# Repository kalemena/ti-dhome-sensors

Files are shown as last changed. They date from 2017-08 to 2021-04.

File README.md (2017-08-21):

# ti-dhome-sensors

Sensors library (use with ti-dhome home automation)

This is custom Sensor unit handler used to capture plenty of metrics and send them over the air to central server.

The initial model units are heavily inspired from the venerable JeeLab Room node.

Sensors are placed in each room and are each monitoring few of below metrics:
* Temparature (1 or more sensor per unit)
* Humidity
* Pressure
* Light
* Move
* TODO: plant humidity
* TODO: gaz
* TODO: pH-meter / CO2

Eventualy, the various measure will serve for:
* control electric heaters
* control VMC (home motorized air flow controler)
* alarms on various actions (plants, etc)

# Hardware

Central board:
* JeeLink (full enclosure, see JeeLab web site)
or
* TBD: Arduino nano 3.3v + radio (RFM12B or RFM69CW)

Base board for sensors:
* model 1 : RFM12B (868Mhz) JeeNode (arduino compatible + radio, see JeeLab web site)
* model 2 : RFM69CW (868Mhz) Arduino pro mini 3.3v or clone

* Batteries: 3xAA or 1xAA+3.3v step-up, or other

Sensors (1+ per board):
* Temparature: DS18B20 (waterproof or not: for some reason waterproof is cheaper!)
* Temparature + Humidity: SHT11 or DHT22 (bigger but with case, and cheaper!)
* Pressure: BMP85
* Light: standard LDR
* Move: TBD
* Plant humidity: TBD
* Gaz: TBD
* pH-meter / CO2: TBD

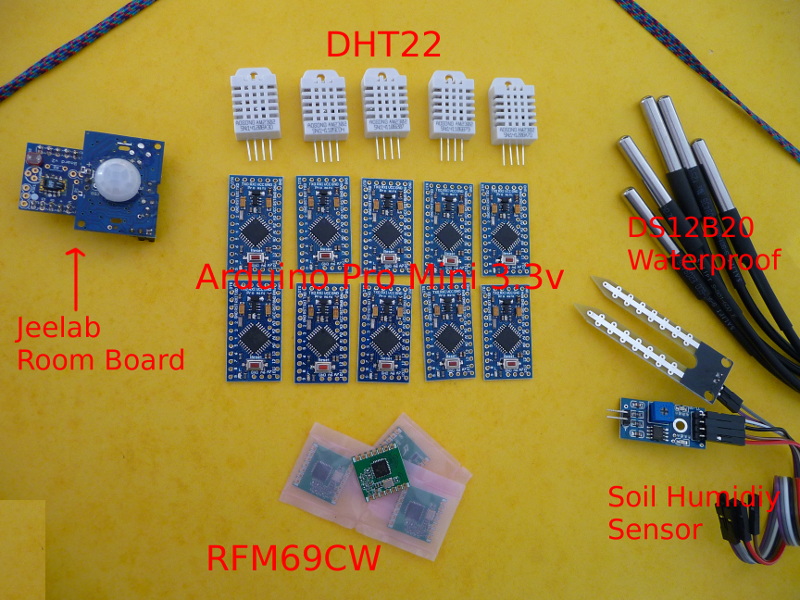
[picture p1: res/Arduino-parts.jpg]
Parts


# Models

## Model 1

[Model 1](model-1) was done in 2010, based entirely on JeeLab work.

## Model 2

[Model 2](model-2) was done in 2015, with little evolution from model 1.

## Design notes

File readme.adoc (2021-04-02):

:toc:

ifdef::env-github[]
:imagesdir: res
endif::[]

= ti-dhome-sensors

Arduino-based sensors library.

This is DIY Sensor unit used to capture plenty of metrics and send them over the air to central unit server.

NOTE: This project is part of a wider link:https://github.com/kalemena/ti-dhome[TiDhome Home Automation] project.

The initial model units are heavily inspired from the venerable JeeLab Room node.

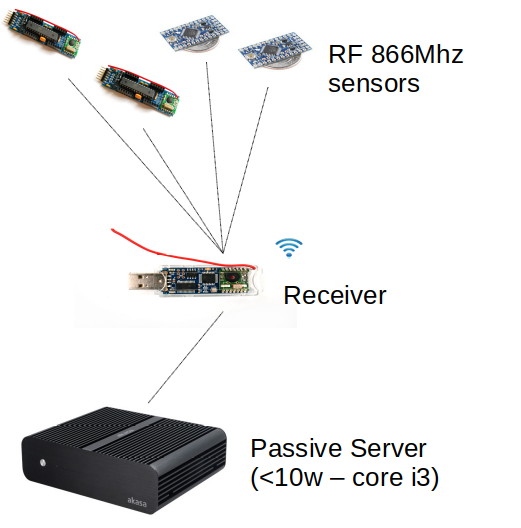
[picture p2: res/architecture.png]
Architecture


== Usage

Sensors are placed in each room and are each monitoring few of below metrics:

* Temparature (1 or more sensor per unit)
* Humidity
* Pressure
* Light
* Move
* TODO: plant humidity
* TODO: gaz
* TODO: pH-meter / CO2

Eventualy, the various measure serve to:

* control electric heaters
* control VMC (home motorized air flow controler)
* alarm on various actions (plants, etc)
* etc

== Hardware

*Central board:*

* JeeLink (full enclosure, see link:https://www.digitalsmarties.net/products/jeelink[JeeLab] web site)

Base board for *sensors model*:

* model 1 : RFM12B (868Mhz) JeeNode (arduino compatible + radio, see JeeLab web site)
* model 2 : RFM69CW (868Mhz) Arduino pro mini 3.3v or clone

*Batteries:* 3xAA or 1xAA+3.3v step-up, or other

*Sensors* (one or more per board):

* Temperature: DS18B20 (waterproof or not)
* Temparature + Humidity: SHT11, DHT22, HTU21
* Pressure: BMP85
* Light: standard LDR
* Move: TBD
* Plant humidity: TBD
* Gaz: TBD
* pH-meter / CO2: TBD

Parts

== Models

=== Model 1

link:model-1[Model 1] was done in 2010, based entirely on JeeLab work.

=== Model 2

link:model-2[Model 2] was done in 2015, with little evolution from model 1.

== More readings

* link:https://www.instructables.com/id/LEIDS-Low-Energy-IOT-Door-Sensor[Check this circuit]

.To Check
[%collapsible]
====
* link:https://www.mysensors.org/apidocs-beta/MyHwESP32_8h_source.html[]
* link:https://www.mysensors.org/build/connect_radio[]
* link:https://github.com/mysensors/MySensors/tree/master[]
====

.Fun IoT projects
[%collapsible]
====
* link:https://www.instructables.com/id/Save-Water-With-the-Shower-Water-Monitor/[]
* link:https://www.instructables.com/id/Battery-Powered-Door-Sensor-With-Home-Automation-I[]
* link:https://www.instructables.com/Autonomous-Solar-powered-Irrigation-Monitoring-Sta[]
====

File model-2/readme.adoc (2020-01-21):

:toc:

ifdef::env-github[]
:imagesdir: ../res
endif::[]

= Description

This sensor was done in 2015, with few evolution from model 2.

The sensors are RFM12B 868Mhz radio transceivers.

One central transceiver receives all measures from all remote sensors.  

= Hardware

Receiver listens on USB tty port:

JeeLink

Plenty emmiter send data using below as base board.

Arduino pro mini 3.3v

Plenty sensors as seen on main page.

Wiring sensors is described at https://github.com/kalemena/arduino-res[arduino-res]

== Breadboard design

Basically initial boards are done like below:

Wiring Breadboard 3xAAA

Wiring Breadboard 1xAAA

== PCB design

Going from Breadboard to PCB using simple double side link:src/pcb[PCB]:

Breadboard

PCB sample look like below:

PCB

Model 2 Top Model 2 Bottom

= Implementation

== How-To - central receiver node

* Open sketch from folder 'src/sketches/sensor_rx_unit/' into Arduino IDE

* Upload sketch to radio-enabled device

* Connect receiver node to USB and find which usb resource connected

[source,bash]
----
$ lsusb
$ dmesg
----

* Allow user access to resource and set speed

[source,bash]
----
$ sudo stty -F /dev/ttyUSB0 57600
$ sudo chmod 777 /dev/ttyUSB0
$ cat /dev/ttyUSB0
----

* Edit test script to point to USB devices or point Node-Red to correct USB device.

== How-To - remote sensor nodes

* Open sketch from folder 'src/sketches/sensor_trx_unit/' into Arduino IDE

* Modify sketch to match sensor devices plugged onto the arduino (ensure pins are correct)

* Upload sketch to radio-enabled device

* ... let it submit metrics over the air ...

== Tests

A small javascript code is done to grab on tty USB port and submit to mqtt queue.

Go to folder 'src/js/' and run below commands:

[source,bash]
----
$ npm install serialport
$ npm install mqtt
$ node pub-sensors.js
----

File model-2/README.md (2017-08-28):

# Description

This sensor was done in 2015, with few evolution from model 1.

The sensors are RFM12B 868Mhz radio transceivers.

One central transceiver receives all measures from all remote sensors.  

# Hardware

Receiver listens on USB tty port:

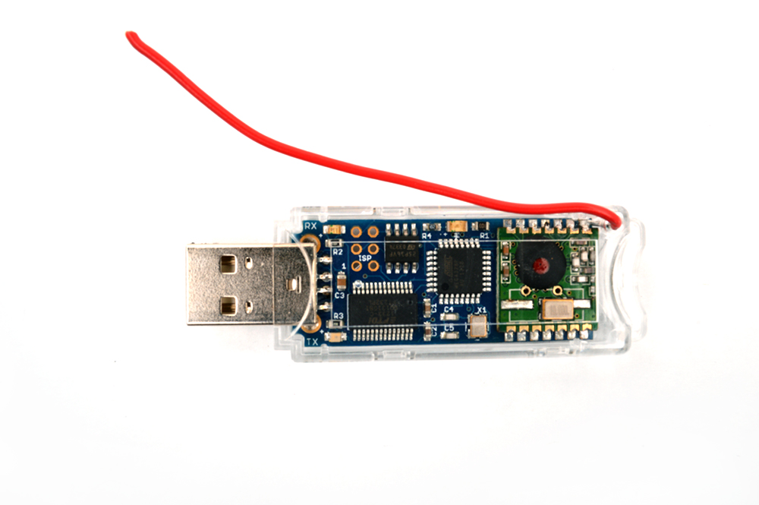
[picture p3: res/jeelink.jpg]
JeeLink


Plenty emmiter send data using below as base board.

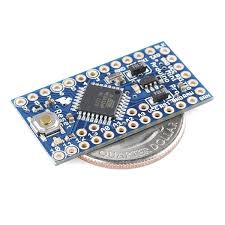
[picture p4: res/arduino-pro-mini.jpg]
Arduino pro mini Arduino Pro Mini 3.3v


Plenty sensors as seen on main page.

Wiring sensors is described at [arduino-res](https://github.com/kalemena/arduino-res)

## Breadboard design

Basically initial boards are done like below:

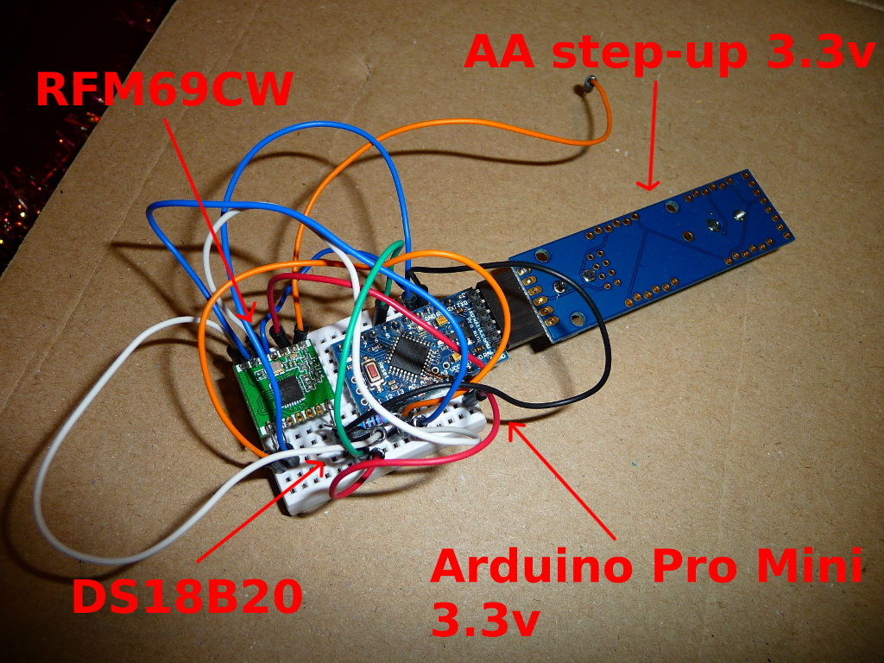
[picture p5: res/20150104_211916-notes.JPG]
Wiring Breadboard 3xAAA


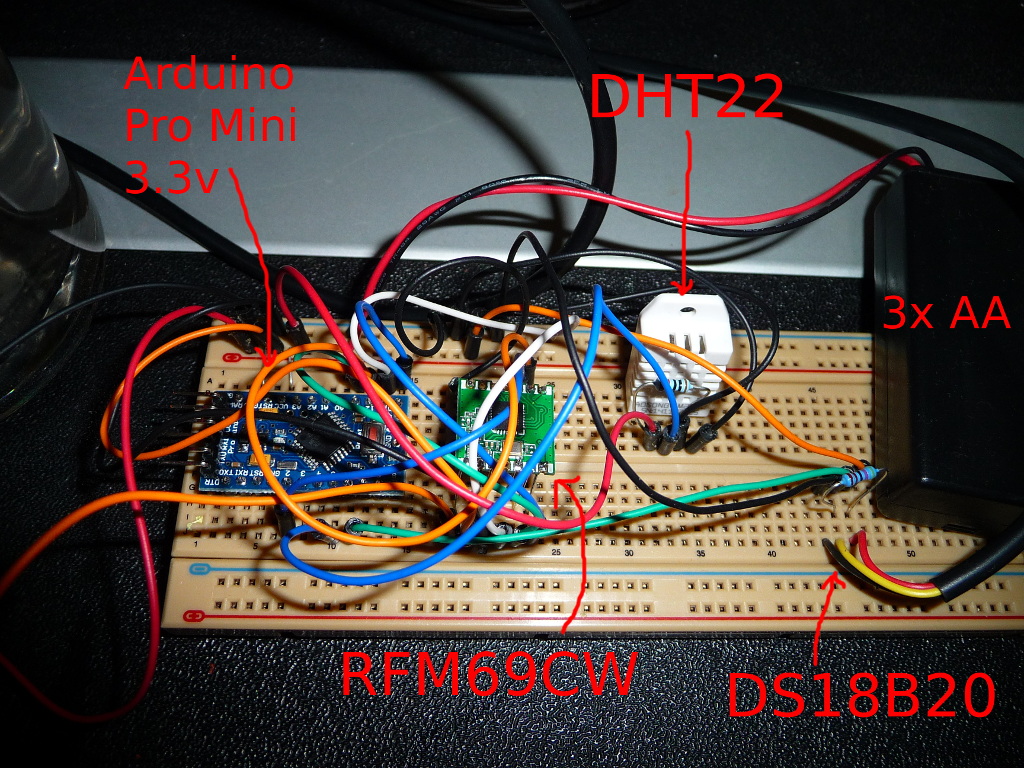
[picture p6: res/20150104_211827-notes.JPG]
Wiring Breadboard 1xAAA


## PCB design

Going from Breadboard to PCB using simple double side PCB:

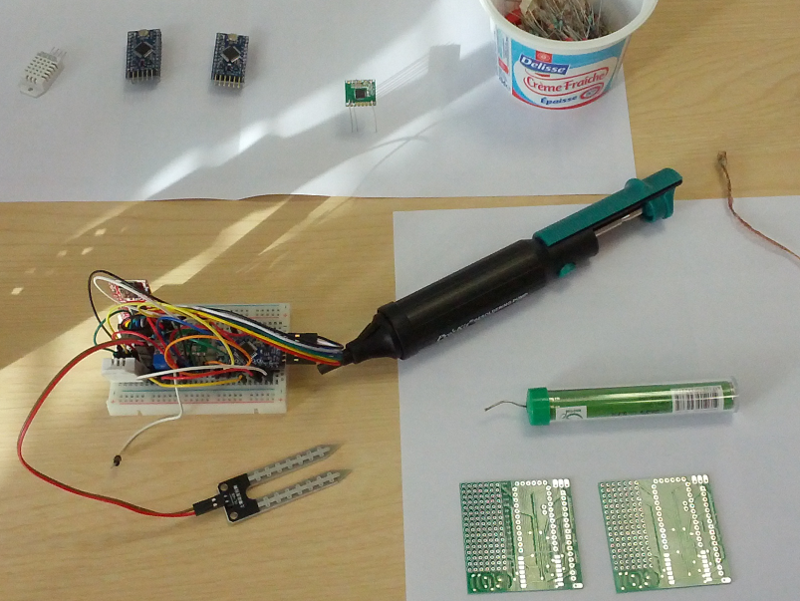
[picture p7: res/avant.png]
Breadboard


PCB sample look like below:

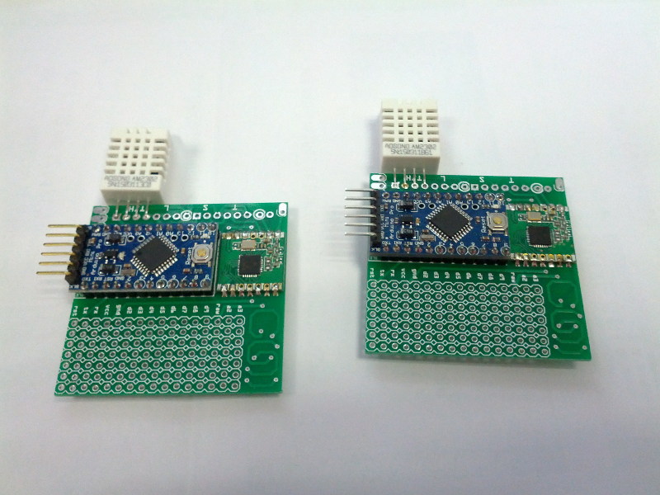
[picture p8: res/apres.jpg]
PCB


# Implementation

## How-To - central receiver node

* Open sketch from folder 'src/sketches/sensor_rx_unit/' into Arduino IDE

* Upload sketch to radio-enabled device

* Connect receiver node to USB and find which usb resource connected

```js
$ lsusb
$ dmesg
```

* Allow user access to resource and set speed

```js
$ sudo stty -F /dev/ttyUSB0 57600
$ sudo chmod 777 /dev/ttyUSB0
$ cat /dev/ttyUSB0
```

* Edit test script to point to USB devices or point Node-Red to correct USB device.

## How-To - remote sensor nodes

* Open sketch from folder 'src/sketches/sensor_trx_unit/' into Arduino IDE

* Modify sketch to match sensor devices plugged onto the arduino (ensure pins are correct)

* Upload sketch to radio-enabled device

* ... let it submit metrics over the air ...

## Tests

A small javascript code is done to grab on tty USB port and submit to mqtt queue.

Go to folder 'src/js/' and run below commands:

```js
$ npm install serialport
$ npm install mqtt
$ node pub-sensors.js
```

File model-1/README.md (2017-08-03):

# Description

This sensor was done in 2010, based entirely on JeeLab work.

The sensors are RFM12B 868Mhz radio transceivers.

One central transceiver receives all measures from all remote sensors.  

# Hardware

Receiver listens on USB tty port:

JeeLink

Plenty emmiter send data using below as base board.

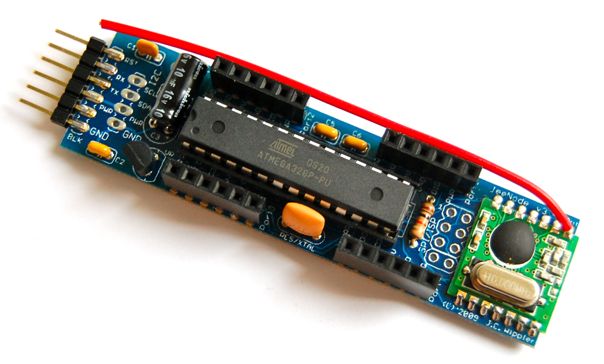
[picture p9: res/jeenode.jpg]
JeeNode


Plenty sensors as seen on main page.

Wiring sensors is described at [arduino-res](https://github.com/kalemena/arduino-res)

# Implementation

## How-To - central receiver node

* Open sketch from folder 'src/sketches/sensor_rx_unit/' into Arduino IDE

* Upload sketch to radio-enabled device

* Connect receiver node to USB and find which usb resource connected

```js
$ lsusb
$ dmesg
```

* Allow user access to resource and set speed

```js
$ sudo stty -F /dev/ttyUSB0 57600
$ sudo chmod 777 /dev/ttyUSB0
$ cat /dev/ttyUSB0
```

* Edit test script to point to USB devices or point Node-Red to correct USB device.

## How-To - remote sensor nodes

* Open sketch from folder 'src/sketches/sensor_trx_unit/' into Arduino IDE

* Modify sketch to match sensor devices plugged onto the arduino (ensure pins are correct)

* Upload sketch to radio-enabled device

* ... let it submit metrics over the air ...

## Tests

A small javascript code is done to grab on tty USB port and submit to mqtt queue.

Go to folder 'src/js/' and run below commands:

```js
$ npm install serialport
$ npm install mqtt
$ node pub-jeenodes.js
```

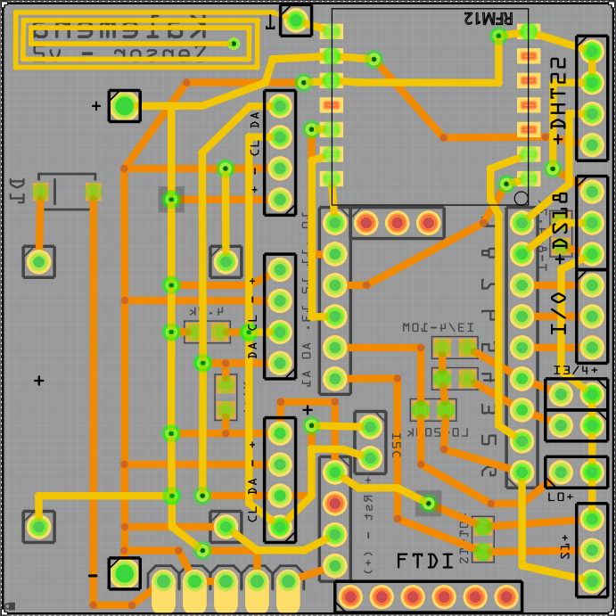
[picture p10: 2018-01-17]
res/model-2-top-fzz.png

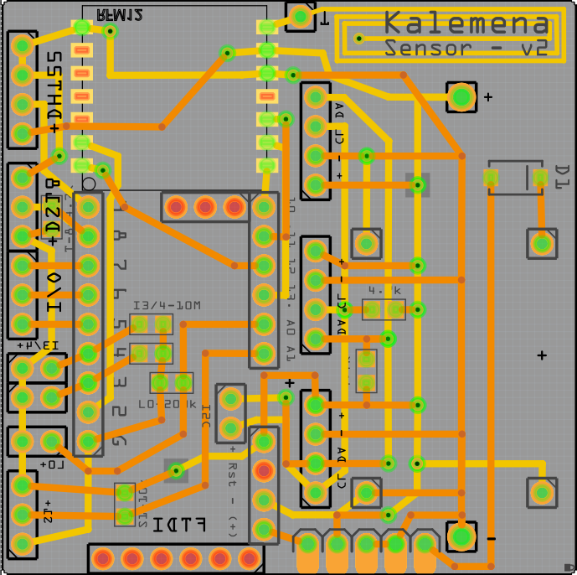
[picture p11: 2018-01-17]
res/model-2-bottom-fzz.png

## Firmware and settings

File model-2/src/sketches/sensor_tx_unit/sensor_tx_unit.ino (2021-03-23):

#define RF69_COMPAT 1 // define this to use the RF69 driver i.s.o. RF12

#include "DHT.h"
#include <JeeLib.h>
#include <PortsSHT11.h>
#include <PortsBMP085.h>
#include <PortsLCD.h>
#include <OneWire.h>
#include <DallasTemperature.h>
#include <Wire.h>
#include "SparkFunHTU21D.h"
#include "TSL2561.h"
#include <avr/sleep.h>
#include <util/atomic.h>
#include <Vcc.h>

#define NODEID    31        // node ID used for this unit
#define NODEGROUP 5         // node GROUP used for this unit
#define REPORT_PERIOD  300  // how often to measure, in tenths of seconds

#define HTU21D_ENABLED true // define I2C plugged on A4/A5
// The address will be different depending on whether you let
// the ADDR pin float (addr 0x39=TSL2561_ADDR_FLOAT), or tie it to ground or vcc. In those cases
// use TSL2561_ADDR_LOW (0x29) or TSL2561_ADDR_HIGH (0x49) respectively
#define TSL2561_ADDR   0
#define SHT11_PORT     0    // define SHT11 port
#define DHT22_PORT     0    // define DHT22 port (9 ?)
#define DS18B20_1_PORT 0    // WARNING 4=DIO port 1, 5=PORT2, 6=PORT3, 7=PORT4 ... 1-wire temperature sensors
#define DS18B20_2_PORT 0    // WARNING ..
#define LDR_PORT       A0   // define LDR on AO,A1,... pin  // WARNING 1=A0, 2=A1, 3=A2, 4=A3
#define LDR_ENABLED    false
#define BMP85_PORT     0    // define BMP85 port
#define SOIL_PORT      A1    // A0, A1 ...
#define SOIL_ENABLED   false
#define TOGGLE_1_PORT  0    // digital port (3/4)
#define TOGGLE_2_PORT  0    // digital port

#define BATTERY_CORRECTION 3.810/3.420 // Measured Vcc by multimeter divided by reported Vcc
// #define BATTERY_CORRECTION 1 // Measured Vcc by multimeter divided by reported Vcc

#define CORRECTION_TEMP_SHT11 0
#define CORRECTION_TEMP_DHT22 0
#define CORRECTION_TEMP_HTU21 -0.2

// set the sync mode to 2 if the fuses are still the Arduino default
// mode 3 (full powerdown) can only be used with 258 CK startup fuses
#define RADIO_SYNC_MODE 2

// Type of data to be reported
enum { TEMPERATURE, HUMIDITY, PRESSURE, LIGHT, BATTERY, SOIL, TOGGLE, TYPE_END };

// The scheduler makes it easy to perform various tasks at various times:
enum { REPORT, TASK_END };
static word schedbuf[TASK_END];
Scheduler scheduler (schedbuf, TASK_END);

struct {
    byte id;  
    byte port; 
    byte type;
    int  value;
} payload;

// count up reports order until next reset
static byte reportCount;

Vcc vcc(BATTERY_CORRECTION);

// Conditional code, depending on which sensors are connected and how:
#if SHT11_PORT
    SHT11 sht11 (SHT11_PORT);
#endif
#if DHT22_PORT
    DHT dht;
#endif
#if DS18B20_1_PORT
    OneWire ds18b20_1 (DS18B20_1_PORT);
    DallasTemperature sensors_1(&ds18b20_1);
    DeviceAddress insideThermometer_1;
    uint8_t oneID_1[8]; 
#endif
#if DS18B20_2_PORT
    OneWire ds18b20_2 (DS18B20_2_PORT);
    DallasTemperature sensors_2(&ds18b20_2);
    DeviceAddress insideThermometer_2;
    uint8_t oneID_2[8]; 
#endif
#if BMP85_PORT
    PortI2C i2c_pressure(BMP85_PORT);
    BMP085 psensor (i2c_pressure, 3); // ultra high resolution
#endif
#if HTU21D_ENABLED
    HTU21D htu21d;
#endif
#if TSL2561_ADDR
  TSL2561 tsl(TSL2561_ADDR);
#endif

// has to be defined because we're using the watchdog for low-power waiting
ISR(WDT_vect) { Sleepy::watchdogEvent(); }

// readout all the sensors and other values, and report
static void measureAndReport() {
    payload.id = NODEID;
    
    payload.type = BATTERY;
    payload.value = vcc.Read_Volts() * 1000; 
    payload.port = 1;
    report();

    #if SHT11_PORT
        sht11.measure(SHT11::HUMI, Sleepy::loseSomeTime(32));        
        sht11.measure(SHT11::TEMP, Sleepy::loseSomeTime(32));
        
        float h, t;
        sht11.calculate(h, t);
        payload.type = TEMPERATURE;
        payload.value = 10 * (t + (float) CORRECTION_TEMP_SHT11);
        payload.port = 31;   
        report();
        
        payload.type = HUMIDITY;
        payload.value = 10 * h;
        payload.port = 41;
        report();
    #endif
    #if DHT22_PORT
      float h2 = dht.getHumidity();
      float t2 = dht.getTemperature();
      
      String eq= "OK";
      String res = dht.getStatusString();
      if(eq.equals(res)) {
        payload.type = TEMPERATURE;
        payload.value = 10 * (t2 + (float) CORRECTION_TEMP_DHT22);
        payload.port = 32;   
        report();
        payload.type = HUMIDITY;
        payload.value = 10 * h2;
        payload.port = 42;
        report();
      }
    #endif
    #if HTU21D_ENABLED
      float h1 = htu21d.readHumidity();
      float t1 = htu21d.readTemperature();
      payload.type = TEMPERATURE;
      payload.value = 10 * (t1 + (float) CORRECTION_TEMP_HTU21);
      payload.port = 33;   
      report();
      payload.type = HUMIDITY;
      payload.value = 10 * h1;
      payload.port = 43;
      report();
    #endif
    #if DS18B20_1_PORT
        payload.type = TEMPERATURE;
        sensors_1.requestTemperatures(); 
        float tempC1 = sensors_1.getTempC(insideThermometer_1);
        payload.value = tempC1 * 10;
        payload.port = 34;
        report();
    #endif
    #if DS18B20_2_PORT
        payload.type = TEMPERATURE;
        sensors_2.requestTemperatures(); 
        float tempC2 = sensors_2.getTempC(insideThermometer_2);
        payload.value = tempC2 * 10;
        payload.port = 35;
        report();
    #endif
    #if BMP85_PORT
        psensor.startMeas(BMP085::TEMP);
        Sleepy::loseSomeTime(16);
        int32_t traw = psensor.getResult(BMP085::TEMP);
    
        psensor.startMeas(BMP085::PRES);
        Sleepy::loseSomeTime(32);
        int32_t praw = psensor.getResult(BMP085::PRES);
        int16_t tempBMP85;
        int32_t pressure;
        psensor.calculate(tempBMP85, pressure);

        payload.type = TEMPERATURE;
        payload.value = tempBMP85;
        payload.port = 36;
        report();
        
        payload.type = PRESSURE;
        payload.value = pressure / 10;
        payload.port = 7;
        report();        
    #endif
    #if LDR_ENABLED
        int32_t LDRReading = analogRead(LDR_PORT); //255 - analogRead(LDR_PORT) / 4;

        payload.type = LIGHT;
        payload.value = LDRReading;
        payload.port = 8;
        report();
    #endif
    #if SOIL_ENABLED
      int32_t sensorValue = analogRead(SOIL_PORT);
      //sensorValue = constrain(sensorValue, 600, 1022);
      //int soil = map(sensorValue, 600, 1022, 100, 0);
      payload.type = SOIL;
      payload.value = sensorValue;
      payload.port = 9;
      report();
    #endif
    #if TOGGLE_1_PORT
      int toggleState1 = digitalRead(TOGGLE_1_PORT);
      payload.type = TOGGLE;
      payload.value = toggleState1;
      payload.port = 10;
      report();
    #endif
    #if TOGGLE_2_PORT
      int toggleState2 = digitalRead(TOGGLE_2_PORT);
      payload.type = TOGGLE;
      payload.value = toggleState2;
      payload.port = 11;
      report();
    #endif
    #if TSL2561_ADDR
      uint16_t tslL = tsl.getLuminosity(TSL2561_VISIBLE);
      payload.type = LIGHT;
      payload.value = tslL;
      payload.port = 20;
      report();
    #endif
}

static void report() {
    rf12_sleep(-1);
    while (!rf12_canSend())
        rf12_recvDone();
    rf12_sendNow(0, &payload, sizeof payload);
    rf12_sendWait(RADIO_SYNC_MODE);
    rf12_sleep(0);

    Sleepy::loseSomeTime(100);
}

void setup () {
    rf12_initialize(NODEID, RF12_868MHZ, NODEGROUP);
    rf12_sleep(0); // power down
 
    #if DHT22_PORT
        dht.setup(DHT22_PORT);
    #endif
    #if DS18B20_1_PORT
        sensors_1.begin();
        boolean bAddress1 = sensors_1.getAddress(insideThermometer_1, 0);
        sensors_1.setResolution(insideThermometer_1, 12);
    #endif
    #if DS18B20_2_PORT
        sensors_2.begin();
        boolean bAddress2 = sensors_2.getAddress(insideThermometer_2, 0);
        sensors_2.setResolution(insideThermometer_2, 12);
    #endif
    #if BMP85_PORT
        psensor.getCalibData();
    #endif
    #if LDR_ENABLED
      pinMode(LDR_PORT, INPUT_PULLUP);
    #endif
    #if TOGGLE_1_PORT
      pinMode(TOGGLE_1_PORT, INPUT);
      // attachInterrupt(digitalPinToInterrupt(TOGGLE_1_PORT), loop, CHANGE);
    #endif
    #if TOGGLE_2_PORT
      pinMode(TOGGLE_2_PORT, INPUT); 
    #endif
    #if HTU21D_ENABLED
      htu21d.begin();
    #endif
    #if TSL2561_ADDR
      tsl.begin();
      tsl.setGain(TSL2561_GAIN_16X);
      tsl.setTiming(TSL2561_INTEGRATIONTIME_13MS);  // shortest integration time (bright light)
      //tsl.setTiming(TSL2561_INTEGRATIONTIME_101MS);  // medium integration time (medium light)
      //tsl.setTiming(TSL2561_INTEGRATIONTIME_402MS);  // longest integration time (dim light)
    #endif
    
    reportCount = 0;
    scheduler.timer(REPORT, 0);    // start the measurement loop going
}

void loop () {
  switch (scheduler.pollWaiting()) 
  {
    case REPORT:
    	reportCount++;
        
    	// reschedule these measurements periodically
    	scheduler.timer(REPORT, REPORT_PERIOD);
    	measureAndReport();
    		    
    	//scheduler.timer(REPORT, 0);
    	break;            
  }
}

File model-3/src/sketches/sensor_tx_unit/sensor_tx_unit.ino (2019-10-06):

#include <JeeLib.h>
#include <RFM69.h>
#include <SPI.h>

#include <Adafruit_Sensor.h>
#include <DHT.h>
#include <DHT_U.h>

#define DEBUG

// RFM69 settings
#define GATEWAYID   50
#define NODEID      35
#define NETWORKID   5
#define FREQUENCY   RF69_868MHZ
#define ENCRYPTKEY  "1234567890123456"  //Encrypt key must be 16 characters
// #define IS_RFM69HW

#define DHTPIN 3
#define DHTTYPE    DHT22

// Watchdog
ISR(WDT_vect) {Sleepy::watchdogEvent();}

RFM69 radio;
DHT_Unified dht(DHTPIN, DHTTYPE);

//Declare local constants
#define LOOP_DELAY   1000

//Data table
typedef struct {
  int    temperature;  //Temperature (°C)
  int    humidity;     //Humidity (%)
  int    voltage;      //Voltage of battery capacity (v)
  byte   measure;      //Measure number (from 0 to 250, +1 each new measurement)
  } Payload;
Payload dataToSend;

const char VERSION[] = "RFM69 transmitter";

/**************************************************************************************/
/* Initialization                                                                     */
/**************************************************************************************/
void setup() {
  //Open a serial connection to display values
  #ifdef DEBUG
    Serial.begin(115200);
    Serial.print("Starting ");
    Serial.println(VERSION);
  #endif

  //Initialize data
  dataToSend.measure = 0;

  //Initialize RFM69 driver
  radio.initialize(FREQUENCY, NODEID, NETWORKID);
  radio.setHighPower();
  radio.encrypt(ENCRYPTKEY);

  #ifdef DEBUG
    radio.readAllRegs();
    Serial.flush();
  #endif

  dht.begin();
  sensor_t sensor;
  dht.temperature().getSensor(&sensor);
  Serial.println(F("------------------------------------"));
  Serial.println(F("Temperature Sensor"));
  Serial.print  (F("Sensor Type: ")); Serial.println(sensor.name);
  Serial.print  (F("Driver Ver:  ")); Serial.println(sensor.version);
  Serial.print  (F("Unique ID:   ")); Serial.println(sensor.sensor_id);
  Serial.print  (F("Max Value:   ")); Serial.print(sensor.max_value); Serial.println(F("°C"));
  Serial.print  (F("Min Value:   ")); Serial.print(sensor.min_value); Serial.println(F("°C"));
  Serial.print  (F("Resolution:  ")); Serial.print(sensor.resolution); Serial.println(F("°C"));
  Serial.println(F("------------------------------------"));
  // Print humidity sensor details.
  dht.humidity().getSensor(&sensor);
  Serial.println(F("Humidity Sensor"));
  Serial.print  (F("Sensor Type: ")); Serial.println(sensor.name);
  Serial.print  (F("Driver Ver:  ")); Serial.println(sensor.version);
  Serial.print  (F("Unique ID:   ")); Serial.println(sensor.sensor_id);
  Serial.print  (F("Max Value:   ")); Serial.print(sensor.max_value); Serial.println(F("%"));
  Serial.print  (F("Min Value:   ")); Serial.print(sensor.min_value); Serial.println(F("%"));
  Serial.print  (F("Resolution:  ")); Serial.print(sensor.resolution); Serial.println(F("%"));
  Serial.println(F("------------------------------------"));

  delay(1000);
  }

/**************************************************************************************/
/* Main loop                                                                          */
/**************************************************************************************/
void loop() {
  // Gather Payload informations
  dataToSend.voltage = getVoltage() / 10.0;
  //dataToSend.temperature = radio.readTemperature(0);

  sensors_event_t event;
  dht.temperature().getEvent(&event);
  if (isnan(event.temperature)) {
    Serial.println(F("Error reading temperature!"));
  } else {
    Serial.print(F("Temperature: "));
    Serial.print(event.temperature);
    Serial.println(F("°C"));
    dataToSend.temperature = event.temperature * 10;
  }
  // Get humidity event and print its value.
  dht.humidity().getEvent(&event);
  if (isnan(event.relative_humidity)) {
    Serial.println(F("Error reading humidity!"));
  } else {
    Serial.print(F("Humidity: "));
    Serial.print(event.relative_humidity);
    Serial.println(F("%"));
    dataToSend.humidity = event.relative_humidity * 10;
  }

  //Insert number of measure
  dataToSend.measure++;
  if (dataToSend.measure > 250) {dataToSend.measure = 0;}

  //Send data on serial link
  #ifdef DEBUG
    Serial.print(dataToSend.temperature, 1);
    Serial.print(" degC");
    Serial.print("   ");
    Serial.print(dataToSend.voltage);
    Serial.print(" v");
    Serial.print("   (");
    Serial.print(dataToSend.measure);
    Serial.println(")");
    Serial.flush();
  #endif

  //Send data
  if (radio.sendWithRetry(GATEWAYID, (const void*)(&dataToSend), sizeof(dataToSend))) {
    #ifdef DEBUG
      Serial.println("Transmission done without problem !");
      Serial.flush();
    #endif
  } else {
    #ifdef DEBUG
      Serial.println("Error with transmission !");
      Serial.flush();
    #endif
  }
  
  //Waiting time before next measurement (minimum 3 seconds)
  radio.sleep();
  //delay(LOOP_DELAY);
  Sleepy::loseSomeTime(LOOP_DELAY);
}

/**************************************************************************************/
/* Allows to get the real Vcc (return value * 100).                                   */
/**************************************************************************************/
int getVoltage() {
  const long InternalReferenceVoltage = 1056L;
  ADMUX = (0<<REFS1) | (1<<REFS0) | (0<<ADLAR) | (1<<MUX3) | (1<<MUX2) | (1<<MUX1) | (0<<MUX0);
  delay(50);  // Let mux settle a little to get a more stable A/D conversion
  //Start a conversion  
  ADCSRA |= _BV( ADSC );
  //Wait for it to complete
  while (((ADCSRA & (1<<ADSC)) != 0));
  //Scale the value
  int result = (((InternalReferenceVoltage * 1023L) / ADC) + 5L) / 10L;
  return result;
}

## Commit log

2017-08-03 Add link to wiring arduinos
2018-01-17 Add PCB designs
2018-03-11 Add corrections in sensor itself (should compare sensors between each others to have them report same values)
    [sensor_tx_unit.ino]
2020-01-21 Add PCB source
    [Board-Sensors-Tx-v12_contour.gm1, Board-Sensors-Tx-v12_copperBottom.gbl, Board-Sensors-Tx-v12_copperTop.gtl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]
